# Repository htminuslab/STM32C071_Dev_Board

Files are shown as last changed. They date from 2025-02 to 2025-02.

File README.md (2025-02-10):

# STM32C071G8 Development Board
This repository contains a tiny STM32C071G8U6N development board developed in [KiCAD8](https://www.kicad.org/). The board took just 1 day to develop and another few hours sorting out some [JLCPCB](https://jlcpcb.com/) issues (wrong/shifted part alignments, selecting parts from [LCSC](https://www.lcsc.com/) etc). 

**Note this board has not yet been manufacturered (JLCPCB gave a quote for £47{UK} for 5 Boards).**

The boards is nothing more but a USB-C connector, STM32C071 and a 3.3v power regulator. Schematics/PBC/Manufacturing data is located in the KiCAD directory.

<p align="center">
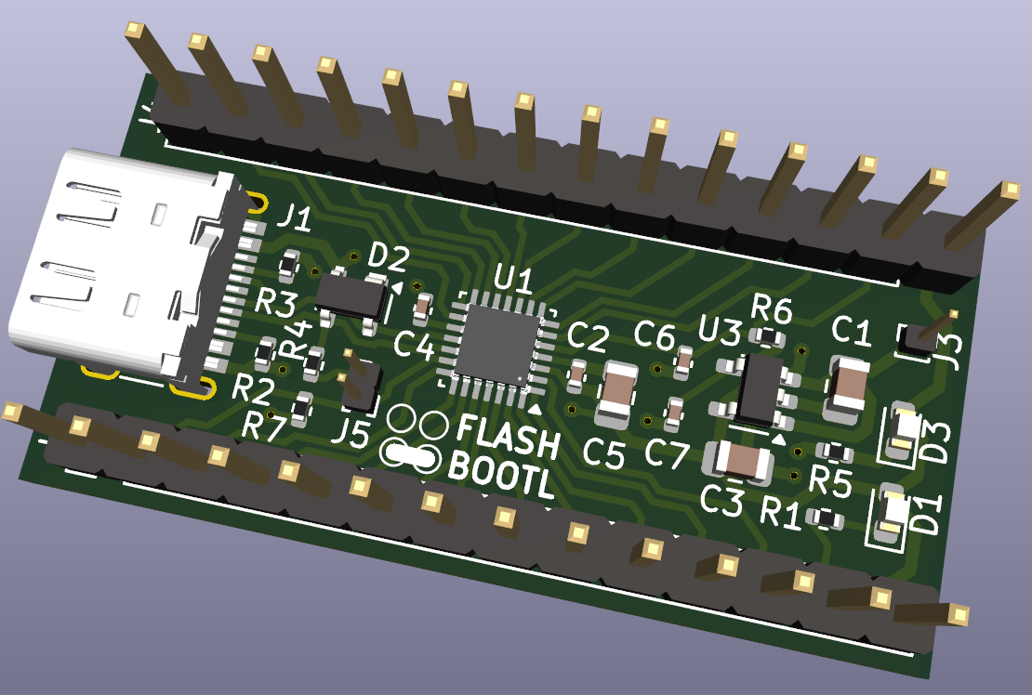
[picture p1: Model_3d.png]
  
</p>

<p align="center">
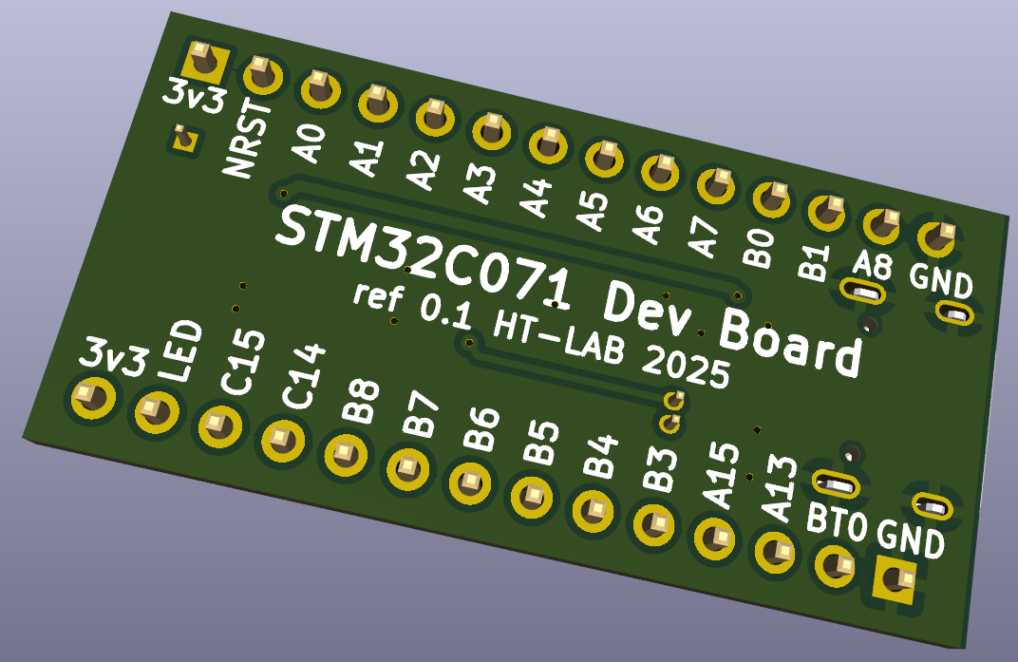
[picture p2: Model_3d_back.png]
  
</p>

## License

See the LICENSE file for details.

## Trademarks

STM32 is a registered trademark of STMicroelectronics International N.V.

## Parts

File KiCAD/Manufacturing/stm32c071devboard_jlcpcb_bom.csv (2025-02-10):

Designator | Comment | Footprint | JLCPCB Part
C1,C3 | 1uF | Capacitor_SMD:C_0805_2012Metric | C1712
C2,C4,C6,C7 | 100nF | Capacitor_SMD:C_0402_1005Metric | C1525
C5 | 4.7uF | Capacitor_SMD:C_0805_2012Metric | C1746
D1 | LED | LED_SMD:LED_0603_1608Metric | C7496819
D3 | LED Red | LED_SMD:LED_0603_1608Metric | C2286
D2 | SP0503BAHT | Package_TO_SOT_SMD:SOT-143 | C7074
J1 | USB_C_Receptacle_USB2.0_14P | ht-lab:USB_C_Receptacle_G-Switch_GT-USB-7010ASV_mod | C2988369
R1,R4,R5 | 1K5 | Resistor_SMD:R_0402_1005Metric | C114451
R2,R3 | 5K1 | Resistor_SMD:R_0402_1005Metric | C105872
R6,R7 | 10K | Resistor_SMD:R_0402_1005Metric | C25531
U1 | STM32C071G8U6N | Package_DFN_QFN:QFN-28_4x4mm_P0.5mm | C707495
U3 | TPS73633DBV | Package_TO_SOT_SMD:SOT-23-5 | C28038

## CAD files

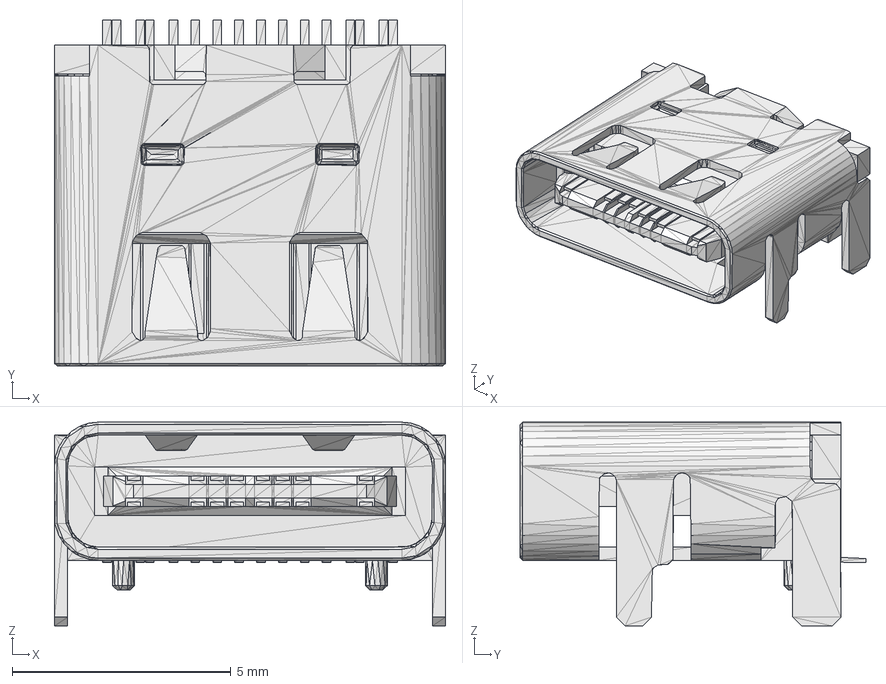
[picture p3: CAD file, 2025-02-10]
KiCAD/USB-C-SMD_G-SWITCH_GT-USB-7010ASV.step
8.94 x 7.90 x 4.66 mm

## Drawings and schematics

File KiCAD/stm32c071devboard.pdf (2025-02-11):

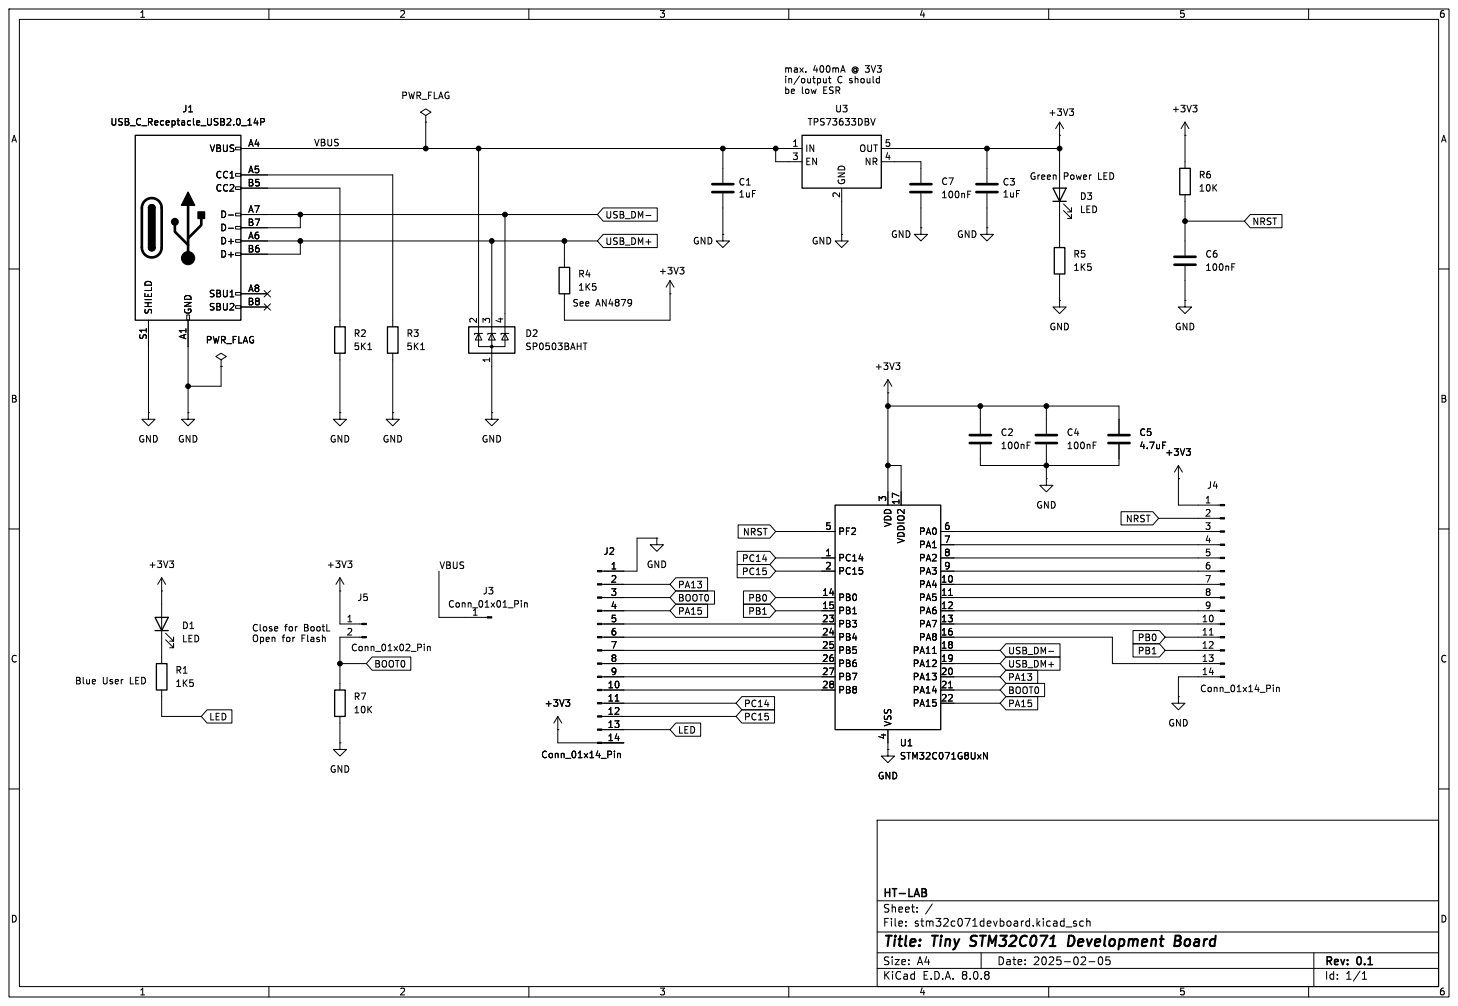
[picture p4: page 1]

2 EN 3 NR 4 OUT 5 U3 TPS73633DBV GND

File: stm32c071devboard.kicad_sch Sheet: / HT-LAB

Id: 1/1 Title: Tiny STM32C071 Development Board

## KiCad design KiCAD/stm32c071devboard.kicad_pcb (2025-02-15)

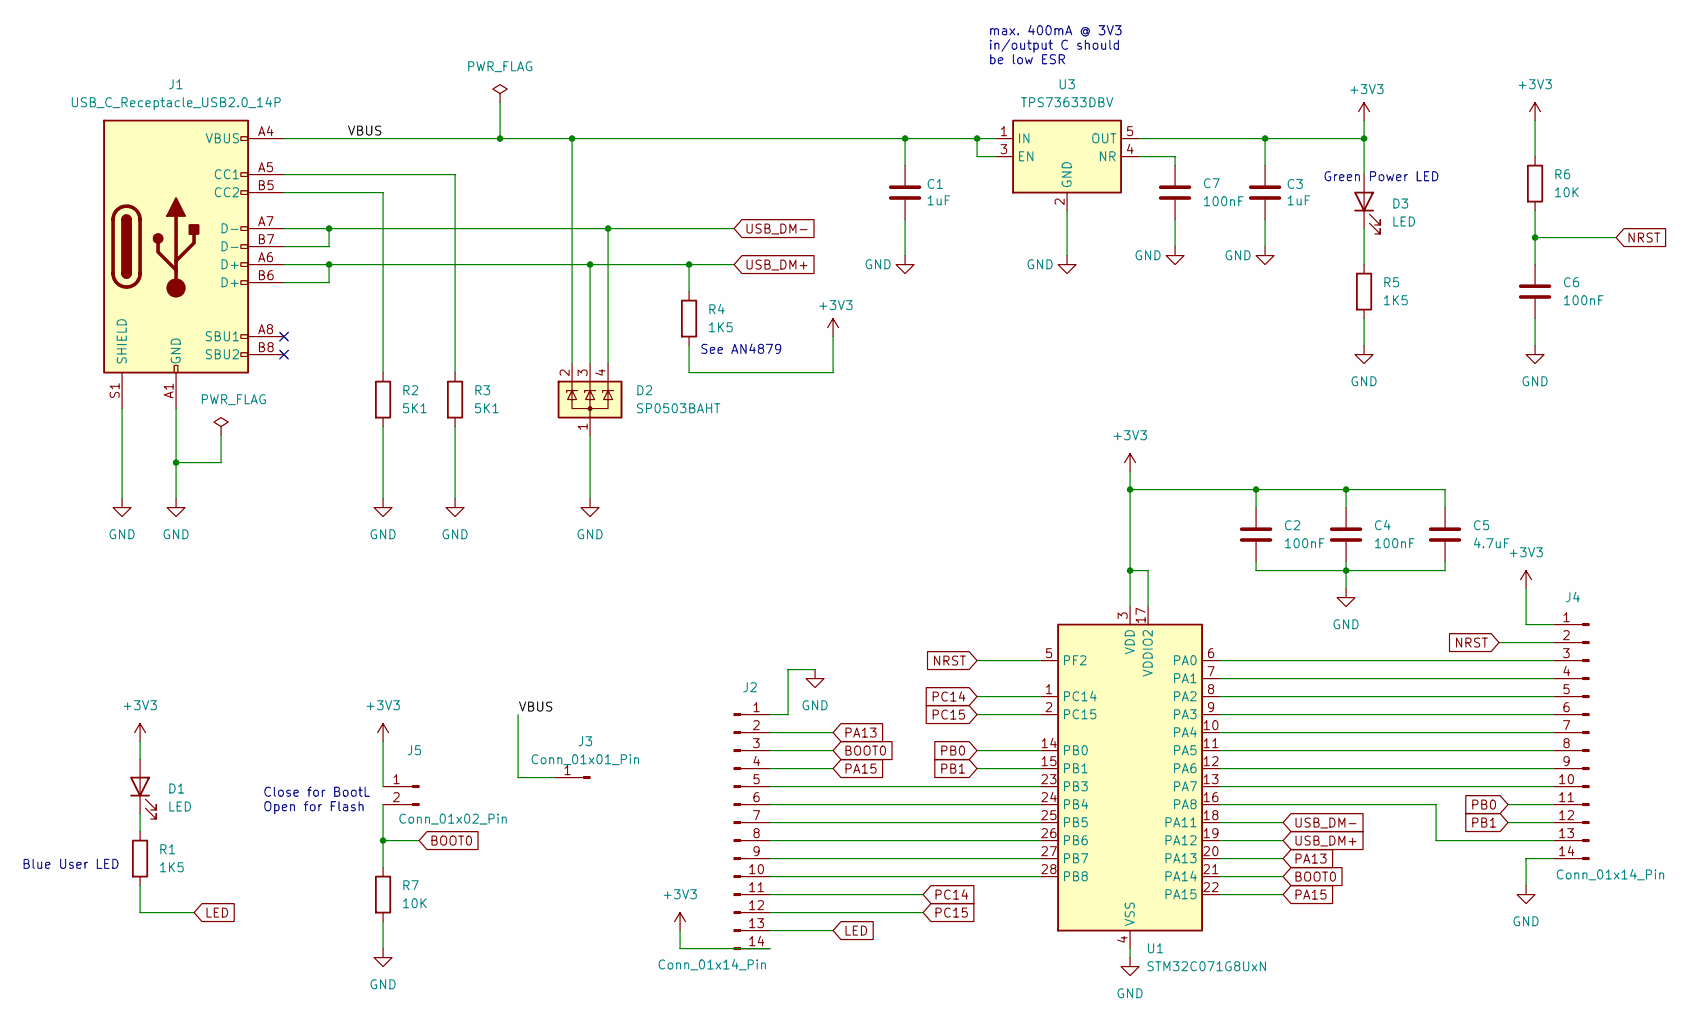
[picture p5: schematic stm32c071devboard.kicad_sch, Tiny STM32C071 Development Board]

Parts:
C1, C3: 1uF; C_0805_2012Metric
C2, C4, C6, C7: 100nF; C_0402_1005Metric
C5: 4.7uF; C_0805_2012Metric
D1, D3: LED; LED_0603_1608Metric
D2: SP0503BAHT; SOT-143
J1: USB_C_Receptacle_USB2.0_14P; USB_C_Receptacle_G-Switch_GT-USB-7010ASV_mod
J2, J4: Conn_01x14_Pin; PinHeader_1x14_P2.54mm_Vertical
J3: Conn_01x01_Pin; PinHeader_1x01_P1.00mm_Vertical
J5: Conn_01x02_Pin; PinHeader_1x02_P1.00mm_Vertical
R1, R4, R5: 1K5; R_0402_1005Metric
R2, R3: 5K1; R_0402_1005Metric
R6, R7: 10K; R_0402_1005Metric
U1: STM32C071G8UxN; QFN-28_4x4mm_P0.5mm
U3: TPS73633DBV; SOT-23-5

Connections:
+3V3: C2.1, C3.1, C4.1, C5.1, D1.2 (A), D3.2 (A), J2.14, J4.1, J5.1, R4.2, R6.1, U1.3 (VDD), U1.17 (VDDIO2), U3.5 (OUT)
/VBUS: C1.1, D2.2 (K), J1.A4 (VBUS), J1.A9 (VBUS), J1.B4 (VBUS), J1.B9 (VBUS), J3.1, U3.1 (IN), U3.3 (EN)
BOOT0: J2.3, J5.2, R7.1, U1.21 (PA14)
GND: C1.2, C2.2, C3.2, C4.2, C5.2, C6.2, C7.2, D2.1 (A), J1.A1 (GND), J1.A12 (GND), J1.B1 (GND), J1.B12 (GND), J1.S1 (SHIELD), J2.1, J4.14, R2.2, R3.2, R5.2, R7.2, U1.4 (VSS), U3.2 (GND)
LED: J2.13, R1.2
NRST: C6.1, J4.2, R6.2, U1.5 (PF2)
unnamed: D1.1 (K), R1.1
unnamed: D3.1 (K), R5.1
unnamed: J1.A5 (CC1), R3.1
unnamed: J1.B5 (CC2), R2.1
unnamed: J2.5, U1.23 (PB3)
unnamed: J2.6, U1.24 (PB4)
unnamed: J2.7, U1.25 (PB5)
unnamed: J2.8, U1.26 (PB6)
unnamed: J2.9, U1.27 (PB7)
unnamed: J2.10, U1.28 (PB8)
unnamed: J4.3, U1.6 (PA0)
unnamed: J4.4, U1.7 (PA1)
unnamed: J4.5, U1.8 (PA2)
unnamed: J4.6, U1.9 (PA3)
unnamed: J4.7, U1.10 (PA4)
unnamed: J4.8, U1.11 (PA5)
unnamed: J4.9, U1.12 (PA6)
unnamed: J4.10, U1.13 (PA7)
unnamed: J4.13, U1.16 (PA8)
unnamed: C7.1, U3.4 (NR)
PA13: J2.2, U1.20 (PA13)
PA15: J2.4, U1.22 (PA15)
PB0: J4.11, U1.14 (PB0)
PB1: J4.12, U1.15 (PB1)
PC14: J2.11, U1.1 (PC14)
PC15: J2.12, U1.2 (PC15)
USB_DM+: D2.3 (K), J1.A6 (D+), J1.B6 (D+), R4.1, U1.19 (PA12)
USB_DM-: D2.4 (K), J1.A7 (D-), J1.B7 (D-), U1.18 (PA11)

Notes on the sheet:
Close for BootL Open for Flash
max. 400mA @ 3V3 in/output C should be low ESR
Blue User LED
See AN4879
Green Power LED

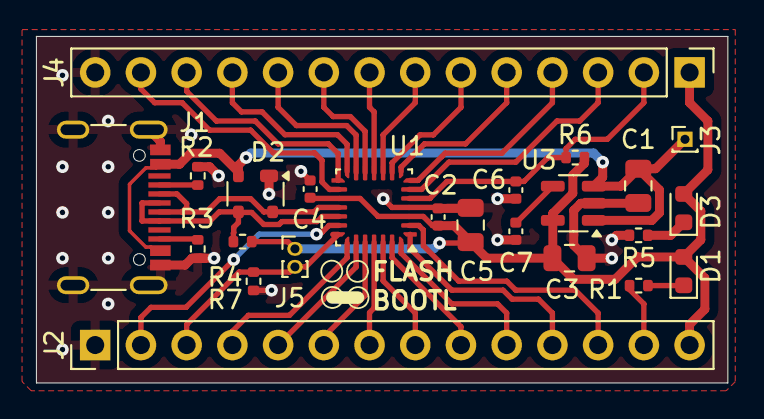
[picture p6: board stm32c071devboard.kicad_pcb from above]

Board: 2 copper layers, 38.4 x 19.2 mm, 24 parts (0 on the bottom side), 34 nets.

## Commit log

2025-02-10 Development Board
    Simple STM32C071G8U6N development board in KiCad8
    [USB-C-SMD_G-SWITCH_GT-USB-7010ASV.step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]
2025-02-11 Fixed 2 pins
    [stm32c071devboard-B_Cu.gbr, stm32c071devboard-B_Mask.gbr, stm32c071devboard-B_Paste.gbr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]
2025-02-15 Minor mods
    Top level ground plane and a few stitching vias
    [stm32c071devboard-B_Cu.gbr, stm32c071devboard-B_Mask.gbr, stm32c071devboard-B_Paste.gbr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]
